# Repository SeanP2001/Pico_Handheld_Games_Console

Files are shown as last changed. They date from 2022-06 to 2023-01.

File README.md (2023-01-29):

# Pico Handheld Games Console

## Table of Contents

* [Introduction](#introduction)
* [Brief](#brief)
* [Circuitry](#circuitry)
  + [Schematic](#schematic)
  + [PCB Design](#pcb-design)
  + [Display Pinout Jumpers](#display-pinout-jumpers)
  + [Soldered PCB](#soldered-pcb)
* [Board Manager & Programming Setup](#board-manager---programming-setup)
* [Code](#code)
* [Enclosure](#enclosure)
  + [CAD Renders](#cad-renders)
  + [3D Printed and Assembled](#3d-printed-and-assembled)
* [Game Library](#game-library)
* [Further Work](#further-work)

## Introduction

I started this project to follow on from my [ATtiny Handheld Games Console](https://github.com/SeanP2001/ATtiny_Handheld_Games_Console). I decided the project was not as accessible as I wanted because programming an ATtiny is not simple enough for a beginner. While the limitations of the ATtiny make it a fun challenge to create games, it would be nice to be able to make something more elaborate.

## Brief

I wanted to make a USB-programmable games console which could be programmed using either MicroPython or C++ (Arduino). I also wanted to use silicone button membranes to give the buttons a more premium feel compared to the tactile buttons on the ATtiny console. I also decided to make a version with a colour LCD display (see the ["LCD_Version"](https://github.com/SeanP2001/Pico_Handheld_Games_Console/tree/LCD_Version) branch).

## Circuitry

### Schematic

<p align="center">
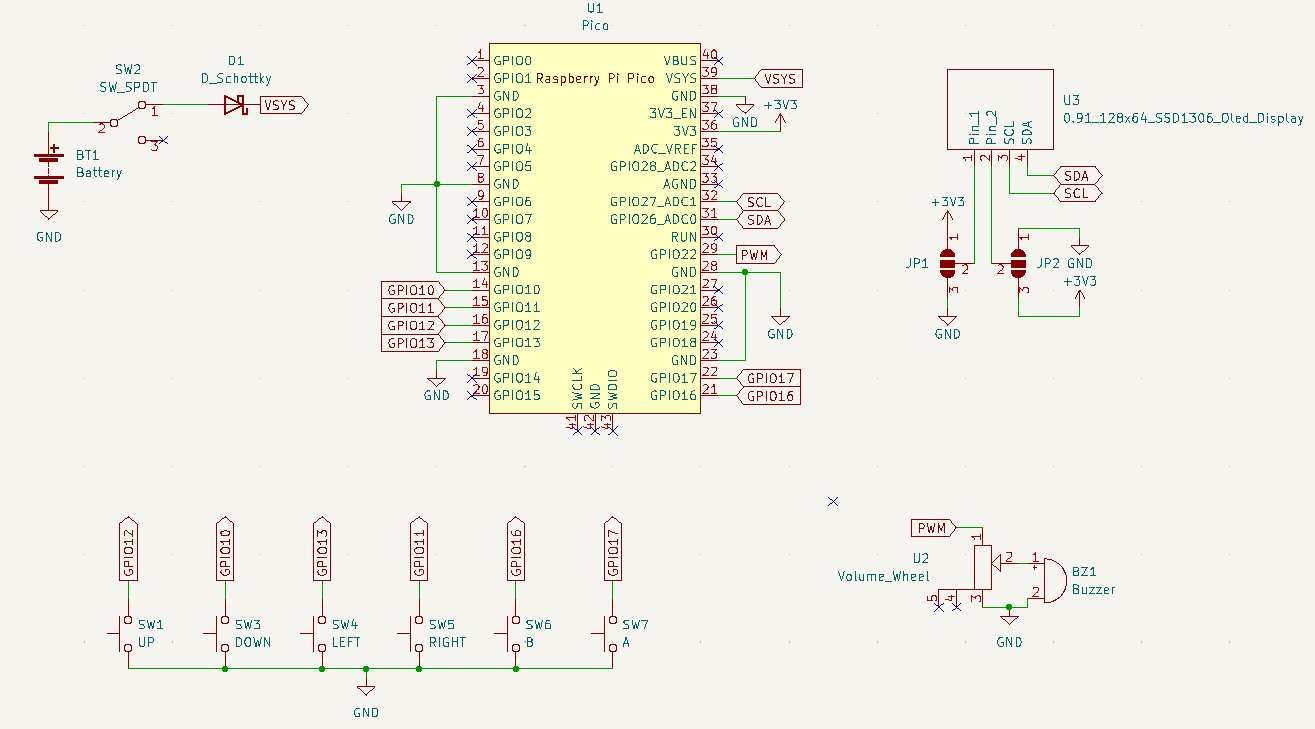
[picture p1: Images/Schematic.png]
  
</p>

### PCB Design

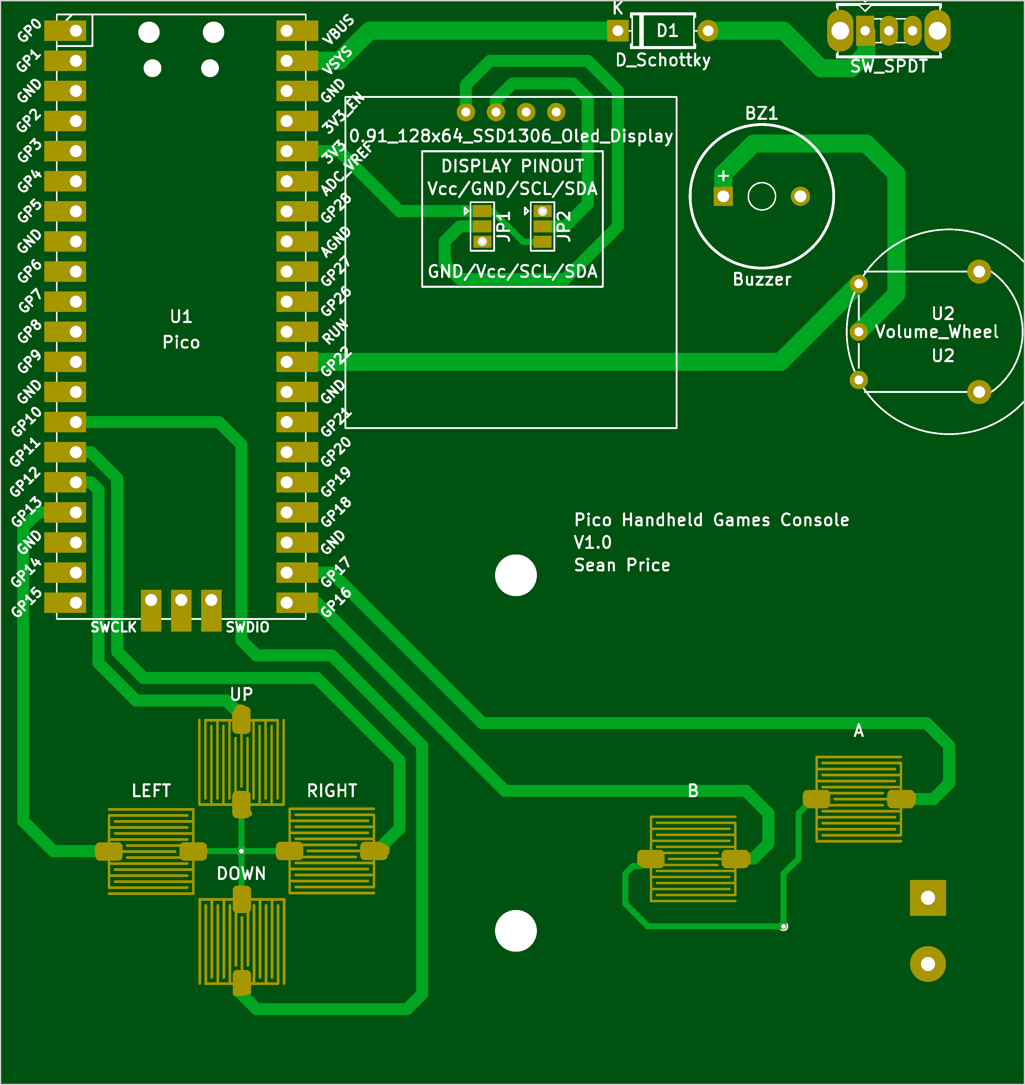
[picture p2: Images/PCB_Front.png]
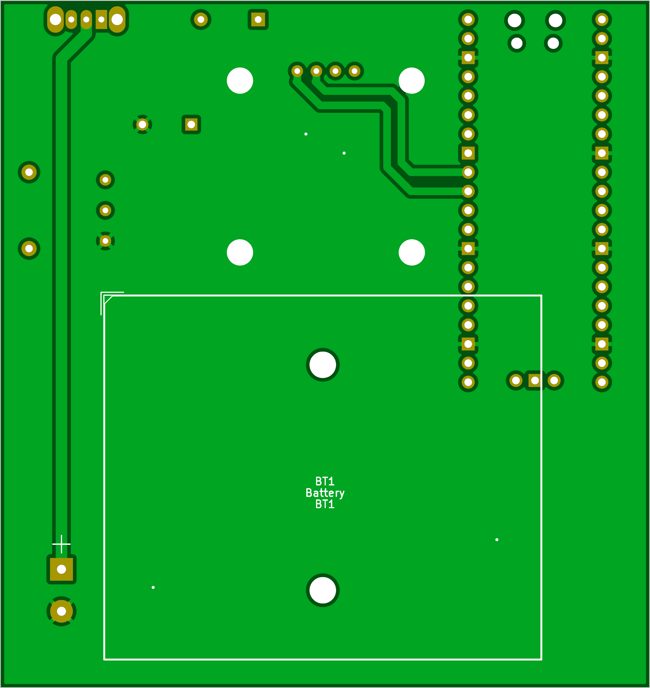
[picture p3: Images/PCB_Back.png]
|  |  |
| --- | --- |

### Display Pinout Jumpers

A feature of the PCB is the jumper connections under the display. The I2C OLED displays do not all have the same pin layout. When you buy a display online, the item you receive may not have the same pinout as the one in the photos. Due to this inconsistency, I designed the board to work with both pinouts. If your display has the pinout (in order) Vcc/GND/SCL/SDA then you need to use solder to bridge the middle pads to the upper pads (shown in blue below). If it is GND/Vcc/SCL/SDA then you need to bridge the middle pads to the lower pads (shown in red below). Once you have done this, use Kapton tape to insulate the solder bridges and prevent them from causing a short circuit on the back of the display.

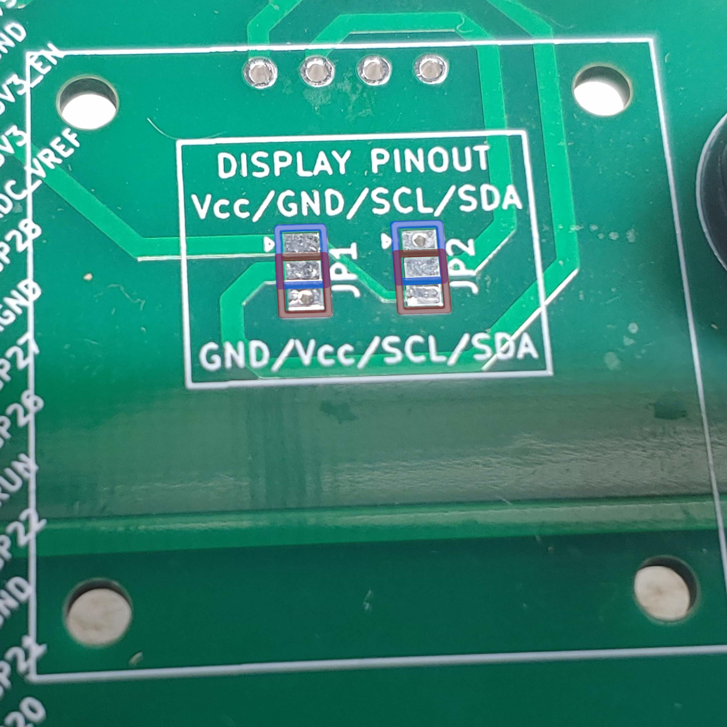
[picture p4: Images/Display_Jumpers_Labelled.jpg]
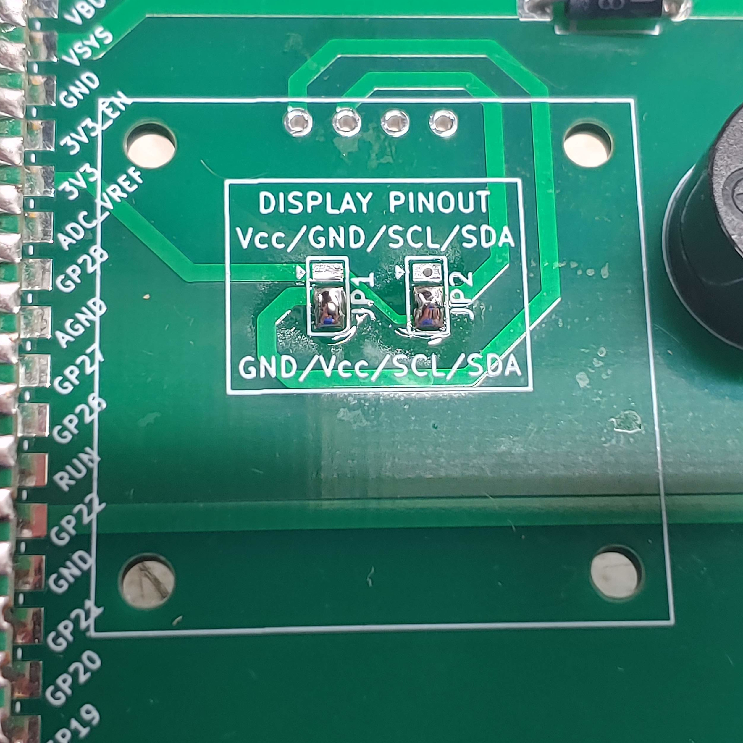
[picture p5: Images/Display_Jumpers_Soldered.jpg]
|  |  |
| --- | --- |

### Soldered PCB

<p align="center">
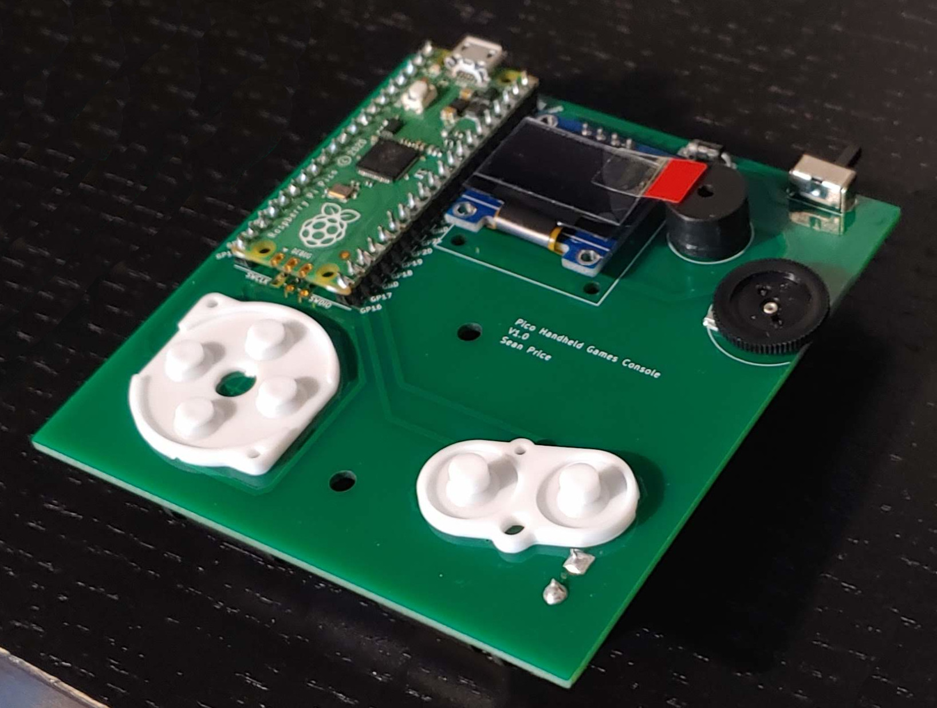
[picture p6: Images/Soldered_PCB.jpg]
 
</p>

## Board Manager & Programming Setup

To program the board in the Arduino IDE, I used the [arduino-pico](https://github.com/earlephilhower/arduino-pico) board manager. I installed this using the method shown in the arduino-pico repository.

For programming the Pico using MicroPython, I followed the fantastic [Official Raspberry Pi Foundation Documentation](https://projects.raspberrypi.org/en/projects/getting-started-with-the-pico). Before this project, I had never used MicroPython, and the information provided was very helpful.

## Code

This repository includes code to test that the buttons, buzzer and display are working correctly. There are two versions; one is an Arduino sketch, and the other is written in MicroPython. When you press a button, the buzzer will sound, and the display will show the name of the button pressed. Recognised buttons are as follows:

- UP
- DOWN
- LEFT
- RIGHT
- A
- B

## Enclosure

### CAD Renders

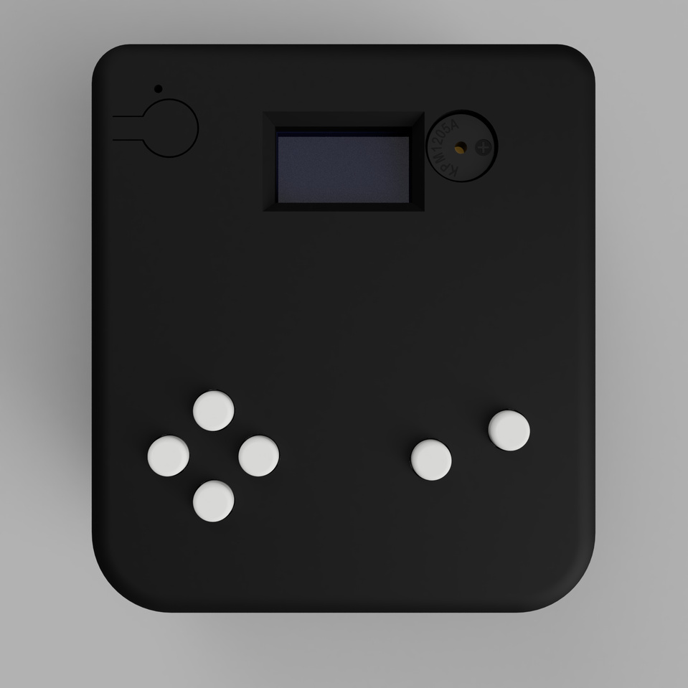
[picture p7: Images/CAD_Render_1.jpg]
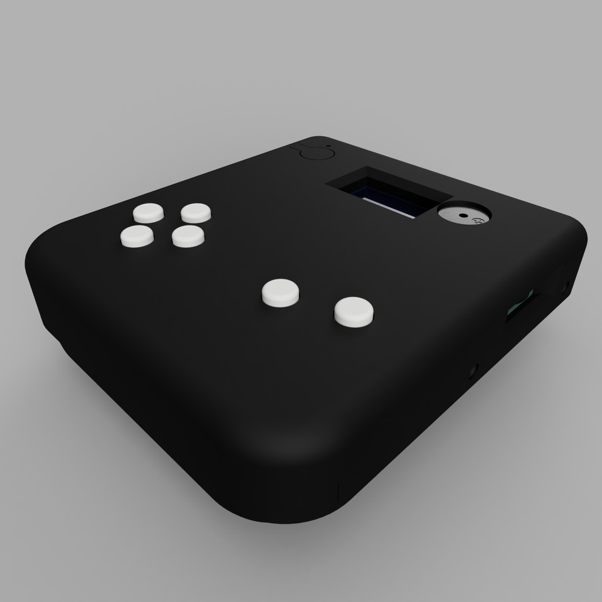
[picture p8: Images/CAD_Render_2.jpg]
|  |  |
| --- | --- |

### 3D Printed and Assembled

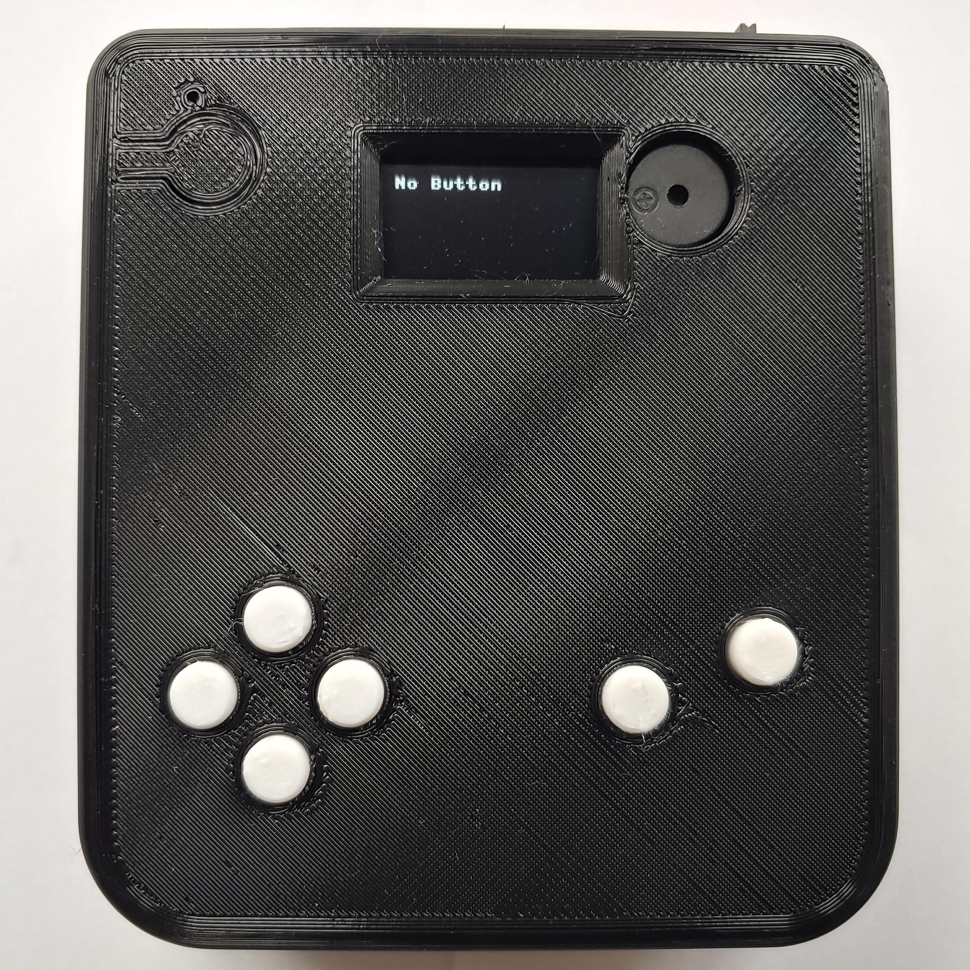
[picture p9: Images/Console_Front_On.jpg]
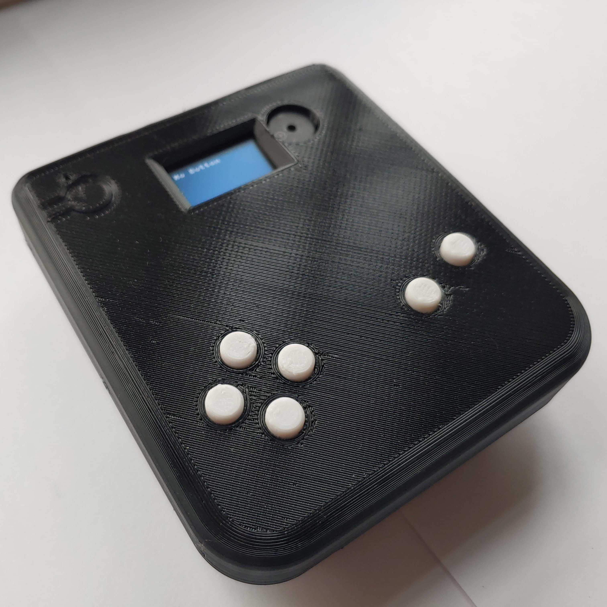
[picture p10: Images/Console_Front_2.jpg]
|  |  |
| --- | --- |
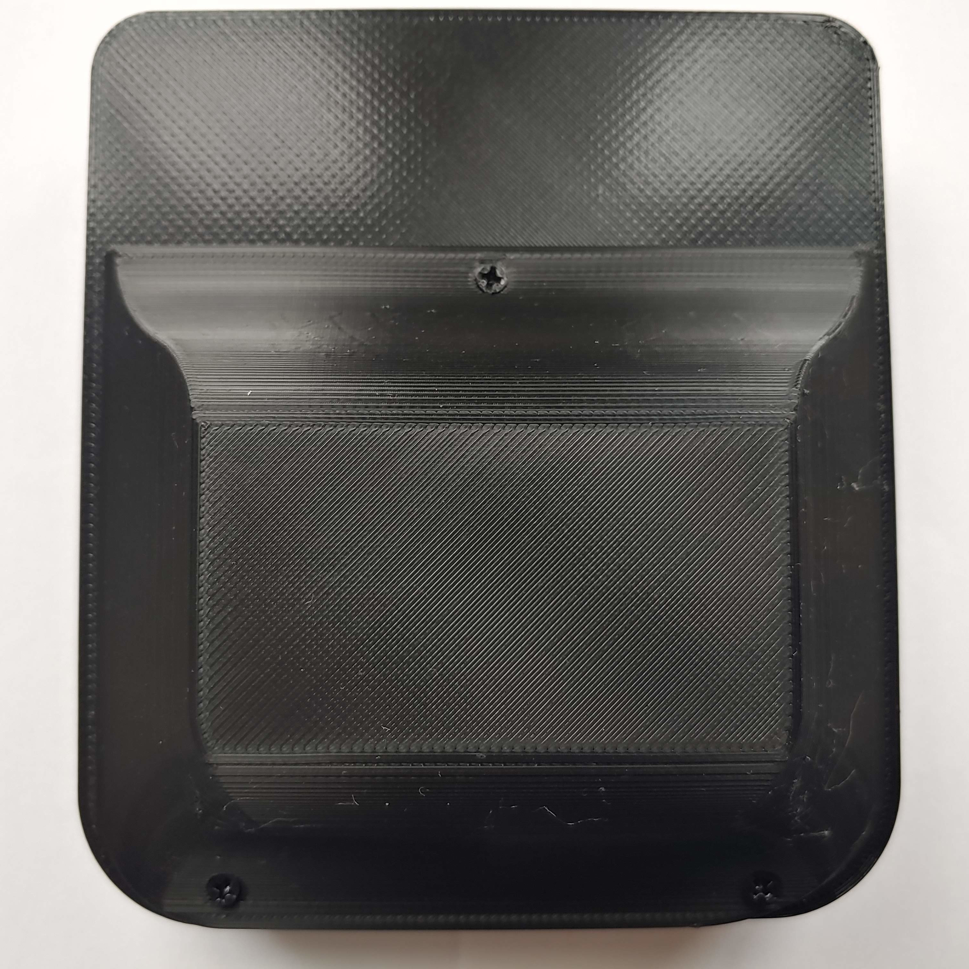
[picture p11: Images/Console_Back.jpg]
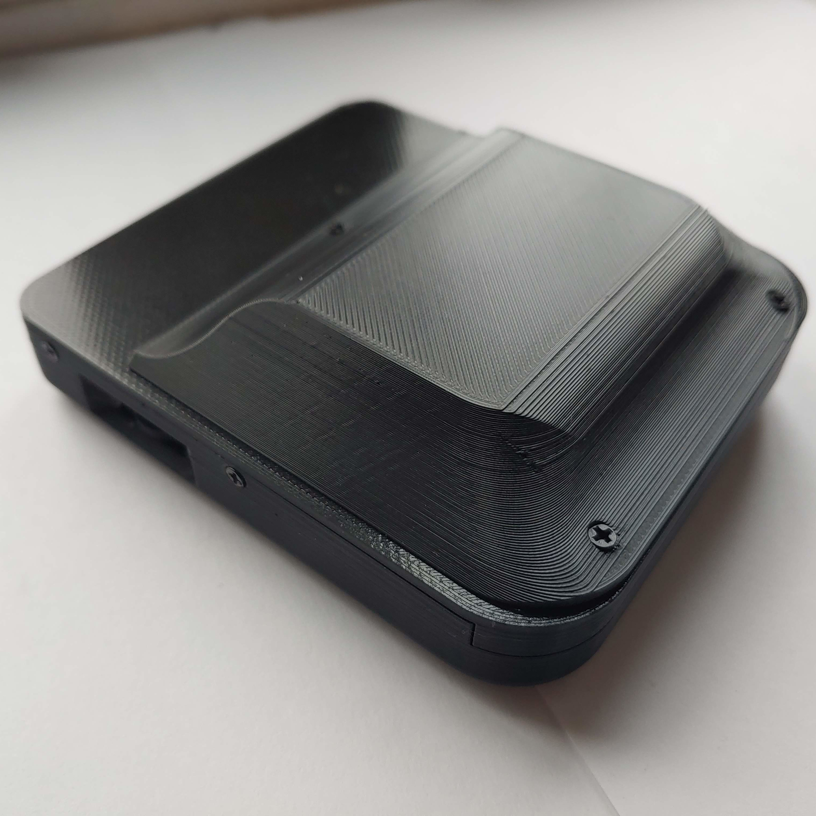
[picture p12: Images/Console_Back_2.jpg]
|  |   |

## Game Library

Currently, there are no games for the Pico Handheld Games Console. If you make any games for this console, please do a "fork and pull request" to add a link to the repository for your game in this section.

## Further Work

This project has achieved its goal of being a more accessible, USB-programmable alternative to my [ATtiny Handheld Games Console](https://github.com/SeanP2001/ATtiny_Handheld_Games_Console).

In future, I would like to push this concept further to make a more advanced console with a larger, colour LCD. I am researching suitable LCDs which can be driven by the Pico (with a frame buffer). To follow the development of this version of the project, please see the ["LCD_Version"](https://github.com/SeanP2001/Pico_Handheld_Games_Console/tree/LCD_Version) branch.

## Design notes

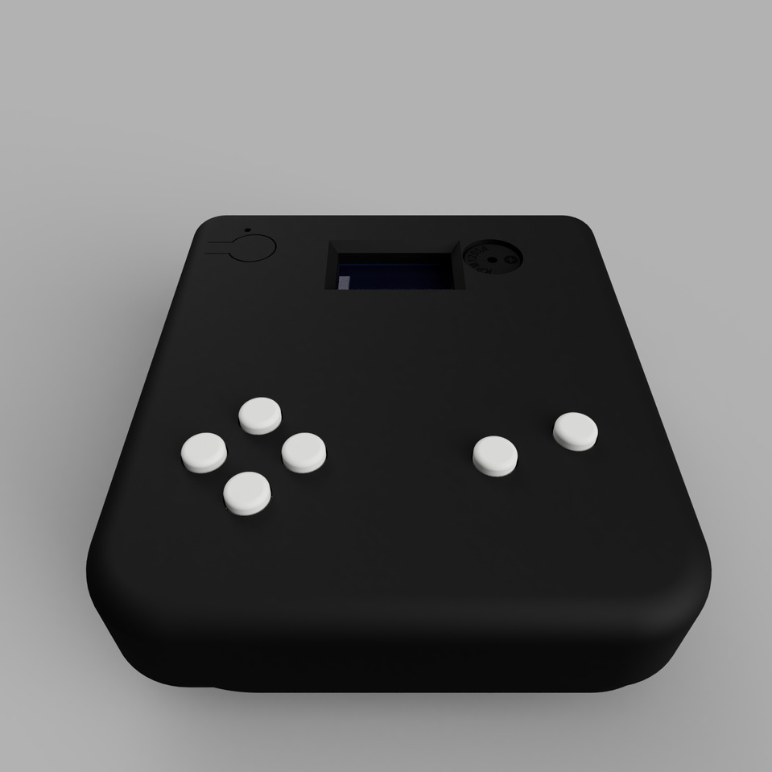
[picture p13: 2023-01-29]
Images/CAD_Render_3.jpg

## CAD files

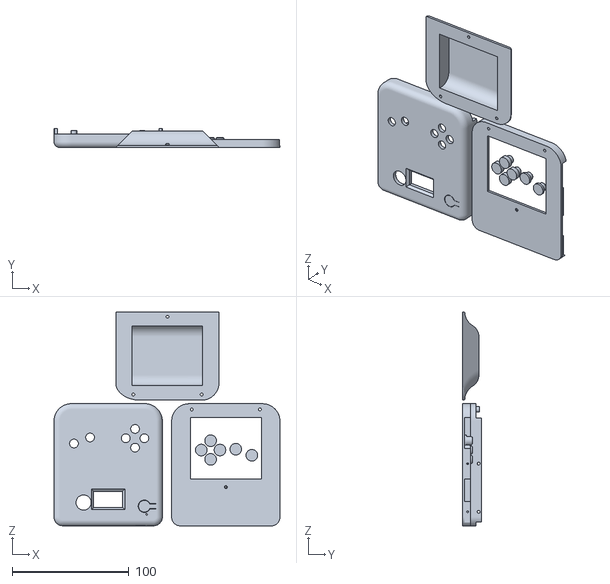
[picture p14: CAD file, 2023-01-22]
Enclosure/Pico_Handheld_Enclosure_Printable.stl
193.7 x 16.5 x 183.2

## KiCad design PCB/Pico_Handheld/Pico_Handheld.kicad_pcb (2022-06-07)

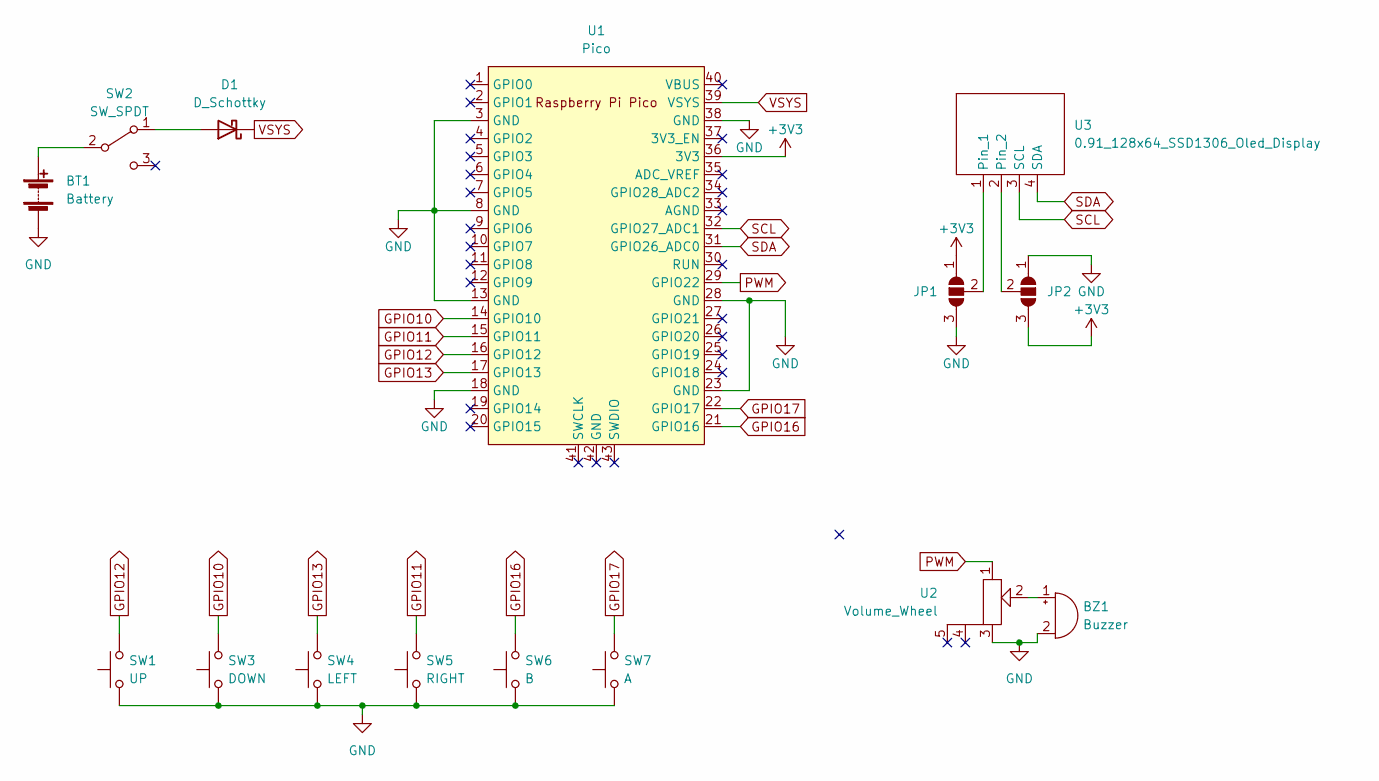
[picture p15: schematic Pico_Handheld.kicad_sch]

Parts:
BT1: Battery; 3xAA_Battery_Holder
BZ1: Buzzer; MagneticBuzzer_ProSignal_ABT-410-RC
D1: D_Schottky; D_A-405_P7.62mm_Horizontal
JP1, JP2: SolderJumper_3_Open; SolderJumper-3_P1.3mm_Open_Pad1.0x1.5mm
SW1: UP; Silicone_Button_Pad
SW2: SW_SPDT; SW_Slide_1P2T_CK_OS102011MS2Q
SW3: DOWN; Silicone_Button_Pad
SW4: LEFT; Silicone_Button_Pad
SW5: RIGHT; Silicone_Button_Pad
SW6: B; Silicone_Button_Pad
SW7: A; Silicone_Button_Pad
U1: Pico; RPi_Pico_SMD_TH
U2: Volume_Wheel
U3: 0.91_128x64_SSD1306_Oled_Display

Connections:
+3V3: JP1.1 (A), JP2.3 (B), U1.36 (3V3)
GND: BT1.2 (-), BZ1.2 (+), JP1.3 (B), JP2.1 (A), SW1.1, SW3.1, SW4.1, SW5.1, SW6.1, SW7.1, U1.3 (GND), U1.8 (GND), U1.13 (GND), U1.18 (GND), U1.23 (GND), U1.28 (GND), U1.38 (GND), U2.3
GPIO10: SW3.2, U1.14 (GPIO10)
GPIO11: SW5.2, U1.15 (GPIO11)
GPIO12: SW1.2, U1.16 (GPIO12)
GPIO13: SW4.2, U1.17 (GPIO13)
GPIO16: SW6.2, U1.21 (GPIO16)
GPIO17: SW7.2, U1.22 (GPIO17)
unnamed: BT1.1 (+), SW2.2 (B)
unnamed: BZ1.1 (-), U2.2
unnamed: D1.2 (A), SW2.1 (A)
unnamed: JP1.2 (C), U3.1
unnamed: JP2.2 (C), U3.2
PWM: U1.29 (GPIO22), U2.1
SCL: U1.32 (GPIO27_ADC1), U3.3 (SCL)
SDA: U1.31 (GPIO26_ADC0), U3.4 (SDA)
VSYS: D1.1 (K), U1.39 (VSYS)

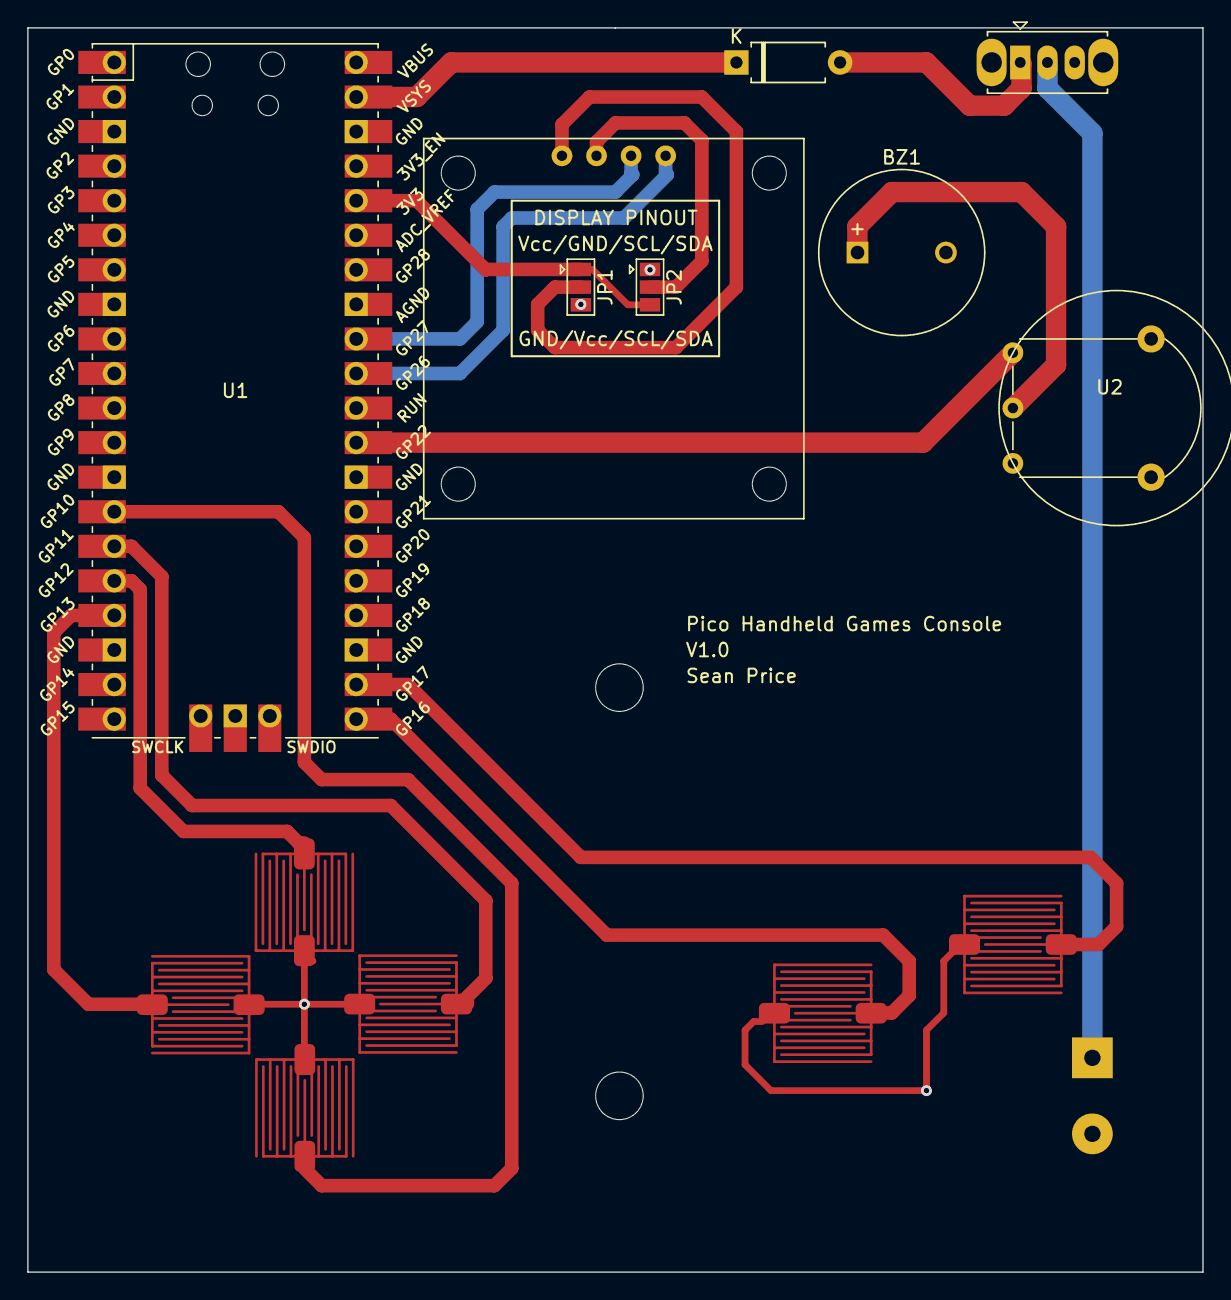
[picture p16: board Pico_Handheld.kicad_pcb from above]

Board: 2 copper layers, 86.4 x 91.4 mm, 15 parts (1 on the bottom side), 17 nets.

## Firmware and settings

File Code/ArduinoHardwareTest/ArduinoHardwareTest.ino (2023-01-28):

#include <SPI.h>
#include <Wire.h>
#include <Adafruit_GFX.h>
#include <Adafruit_SSD1306.h>

#define SCREEN_WIDTH 128 // OLED display width, in pixels
#define SCREEN_HEIGHT 64 // OLED display height, in pixels

#define OLED_RESET     -1 // Reset pin # (or -1 if sharing Arduino reset pin)
#define SCREEN_ADDRESS 0x3c ///< See datasheet for Address; 0x3D for 128x64, 0x3C for 128x32
Adafruit_SSD1306 display(SCREEN_WIDTH, SCREEN_HEIGHT, &Wire, OLED_RESET);

int upButton = 12;
int downButton = 10;
int leftButton = 13;
int rightButton = 11;
int aButton = 17;
int bButton = 16;

int buzzer = 22;

void setup() {

  pinMode(upButton, INPUT_PULLUP);
  pinMode(downButton, INPUT_PULLUP);
  pinMode(leftButton, INPUT_PULLUP);
  pinMode(rightButton, INPUT_PULLUP);
  pinMode(aButton, INPUT_PULLUP);
  pinMode(bButton, INPUT_PULLUP);

  pinMode(buzzer, OUTPUT);
  
  display.begin(SSD1306_SWITCHCAPVCC, SCREEN_ADDRESS);

  display.clearDisplay();
  display.display();

  display.setTextSize(2);
  display.setTextColor(WHITE);
}

void loop() {
  display.clearDisplay(); 
  noTone(buzzer);
  display.setCursor(0,16);

  if (digitalRead(upButton) == HIGH)
  {
    display.println("Up Button");
    tone(buzzer, 2000);
  }
  else if (digitalRead(downButton) == HIGH)
  {
    display.println("Down Button");
    tone(buzzer, 2000);
  }
  else if (digitalRead(leftButton) == HIGH)
  {
    display.println("Left Button");
    tone(buzzer, 2000);
  }
  else if (digitalRead(rightButton) == HIGH)
  {
    display.println("Right Button");
    tone(buzzer, 2000);
  }
  else if (digitalRead(aButton) == HIGH)
  {
    display.println("A Button");
    tone(buzzer, 2000);
  }
  else if (digitalRead(bButton) == HIGH)
  {
    display.println("B Button");
    tone(buzzer, 2000);
  }
  else
  {
    display.println("No Button");
  }

  display.display();
  delay(1000);

}

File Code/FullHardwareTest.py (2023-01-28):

import time
from machine import Pin, I2C, PWM
from ssd1306 import SSD1306_I2C

#-----------------------------------------------------------------
class Button:
    def __init__(self, pinNo):
        self.button = Pin(pinNo, Pin.IN, Pin.PULL_UP)       
        
    def isPressed(self):
        if (self.button.value() == 0):
            return True
        else:
            return False
#-----------------------------------------------------------------
        
upButton = Button(12)
downButton = Button(10)
leftButton = Button(13)
rightButton = Button(11)
aButton = Button(17)
bButton = Button(16)

#-----------------------------------------------------------------

i2c = I2C(1, sda=Pin(26), scl=Pin(27), freq=400000) # get the I2C address

oled = SSD1306_I2C(128, 64, i2c)

#-----------------------------------------------------------------

buzzer = PWM(Pin(22))
buzzer.freq(2000)
buzzer.duty_u16(0)     # turned off to start

#-----------------------------------------------------------------

oled.fill(0)
oled.show()

while(1):
    if (upButton.isPressed()):
        oled.text("Up Button", 0, 0)
        buzzer.duty_u16(1000)            # turn the buzzer on at max volume
    elif (downButton.isPressed()):
        oled.text("Down Button", 0, 0)
        buzzer.duty_u16(1000)            # turn the buzzer on at max volume
    elif (leftButton.isPressed()):
        oled.text("Left Button", 0, 0)
        buzzer.duty_u16(1000)            # turn the buzzer on at max volume
    elif (rightButton.isPressed()):
        oled.text("Right Button", 0, 0)
        buzzer.duty_u16(1000)            # turn the buzzer on at max volume
    elif (aButton.isPressed()):
        oled.text("A Button", 0, 0)
        buzzer.duty_u16(1000)            # turn the buzzer on at max volume
    elif (bButton.isPressed()):
        oled.text("B Button", 0, 0)
        buzzer.duty_u16(1000)            # turn the buzzer on at max volume
    else:
        oled.text("No Button", 0, 0)
        
    oled.show()        
    time.sleep(1)
    buzzer.duty_u16(0)  # turn the buzzer off
    oled.fill(0)        # clear the screen
    oled.show()

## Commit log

2022-06-02 V0.1.0 Designed PCB
    [Pico_Handheld.kicad_pcb, Pico_Handheld.kicad_sch]
2022-06-07 V0.1.1 Finalised PCB V1.0
    [Pico_Handheld-B_Cu.gbl, Pico_Handheld-B_Mask.gbs, Pico_Handheld-B_Paste.gbp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]
2022-09-26 V0.2.0 Updated Schematic to Use an ILI9341 TFT LCD
    [Pico_Handheld.kicad_sch]
2022-09-26 V0.3.0 Added MicroPython ButtonTest with ILI9341 Display
2022-09-26 V0.4.0 Added C++ ButtonTest and ColourTest with ILI9341 Display
2023-01-22 V0.7.0 CAD Modelled Enclosure (For OLED Version)
    [Pico_Handheld_Enclosure_Printable.stl]
2023-01-28 V0.7.1 3D Printed Enclosure and Assembled Console
2023-01-28 V0.7.2 Split PCB Designs into OLED and LCD Variants
    [Pico_Handheld.kicad_pcb, Pico_Handheld.kicad_sch]
2023-01-28 V8.0.1 Removed the LCD Variant from the OLED Branch
    [Pico_Handheld.kicad_pcb, Pico_Handheld.kicad_sch]
